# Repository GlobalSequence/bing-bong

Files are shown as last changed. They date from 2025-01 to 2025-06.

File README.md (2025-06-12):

[](https://github.com/GlobalSequence/bing-bong/blob/master/photo.png)

## Intro

Bing Bong is a digital drum synthesizer module for Eurorack synthesizers which generates percussive sounds using two different synthesis methods:

- Phase modulation synthesis
- Physical modeling synthesis

This module is intended to offer a versatile array of sounds ranging anywhere from organic substrates to purely synthesized tones. With a wide frequency range, it can fill many roles in an electronic drum kit. Both atonal and tonal sounds can be produced, ranging anywhere from quick transient bursts to long sustained sounds. 

## Block Diagram

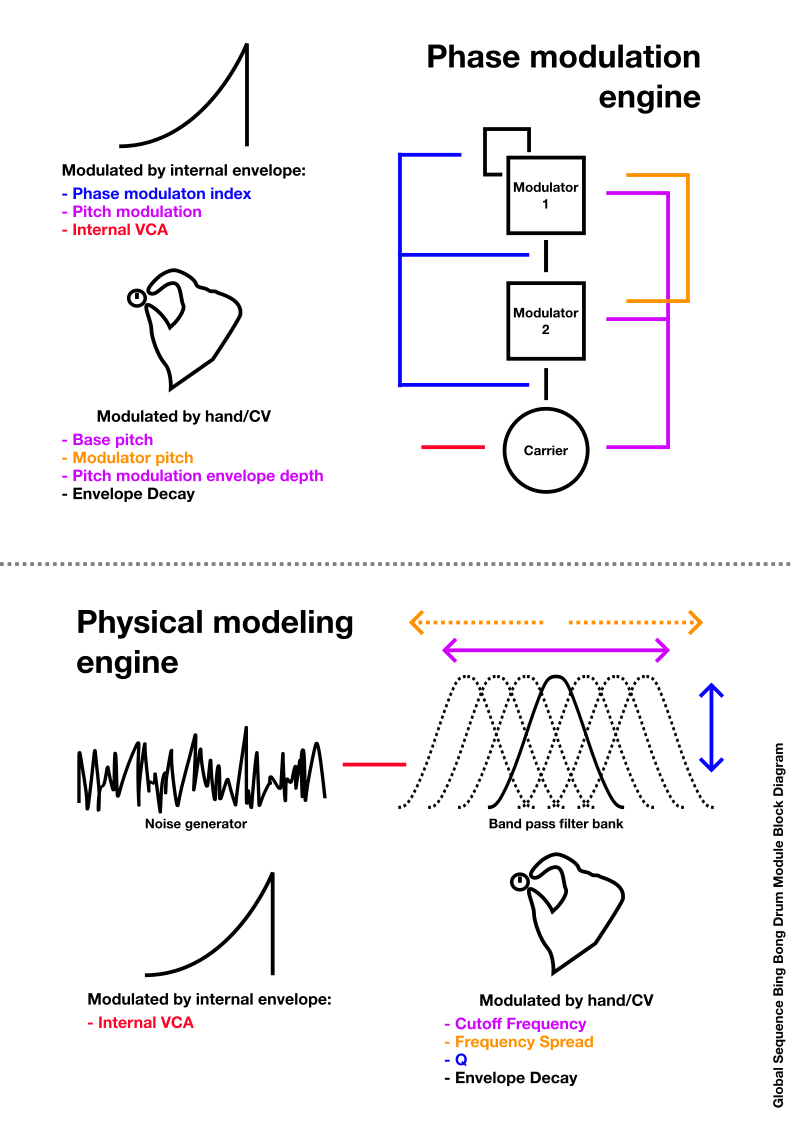
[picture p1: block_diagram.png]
[](https://github.com/GlobalSequence/bing-bong/blob/master/block_diagram.png)

## Features
- Versatile drum voice for modular synthesizers
- Switchable phase modulation and physical modeling sound engines
- Mechanical key switch for tactile manual triggering
- CV inputs for all parameters
- 12 bit, 48khz sound

## Synthesis Engines 
### Phase Modulation
#### Overview
The Phase modulation engine is made up of three sine wave operators, fed into one another in series, The first modulator has operator feedback.

The modulation index of each modulator is controlled by the envelope, with each index being set to maximum when the module is triggered, before fading to an index of 0 when the envelope has faded away, effectively creating a sharp sound which softens over time. 

This engine can be used to achieve deep raunchy kick drums, clean ringing chimes, metallic clangs, chirps, and more.
#### Parameters
##### Carrier 
This may be somewhat misleading as this parameter controls the base pitch of the entire voice. 
##### Modulator
Move the pitch of the two modulator oscillators relative to the pitch of the carrier oscillator. The first modulator is always an octave higher than the second modulator. 

When set very high, the carrier frequency (if also set very high) may push the modulator frequencies into interesting territories, or even to oblivion. There is no anti-aliasing in this module, and that's a feature, not a bug! 
##### Pitch Mod
Set the depth by which the envelope affects the pitch of all oscillators. With this parameter set to zero, there is no pitch modulation. As the pitch mod is turned up, the drum hit will start at increasingly higher frequencies and fall to the lowest frequency at the end of the envelope's decay.
##### Decay
Sets the decay time of the envelope. The envelope modulates these other parameters in the engine:
- Modulation index
- Pitch modulation amount
- Internal VCA
By shortening or lengthening the decay time, you can dramatically alter the trajectory of the sound, because all of the parameters dependent on it.

The decay time can be set from a few milliseconds to several seconds, turning the drum module into a sort of faux-drone that can be used for effects and sound scapes, should you wish to venture into that territory.

### Physical Modeling
#### Overview
The physical modeling engine is comprised of a white noise source which is fed into seven parallel band pass filters with a variable Q. 

This engine can be used to achieve organic drum tones ranging from membrane drums of many shapes and sizes, to percussive surfaces made of other materials like glass, metal, wood, and more. 
#### Parameters
##### Cutoff
This sets the cutoff frequency of the central and peripheral band pass filters. 
##### Spread
Pushes the 6 peripheral band pass filters away from the central filter. 3 peripheral filters are set to a lower frequency than the central filter, while the other 3 are higher. The second and third peripheral filters are twice and thrice as far from the central filter as the first on both the higher and lower end, meaning that the filters are always evenly spaced on the frequency spectrum.

When this parameter is set to zero, all of the filters are at the same frequency. 
##### Q
Sets the emphasis of all band pass filters using feedback. As the Q is turned, up, the center frequency of each filter is amplified to the point of self oscillation, making the atonal noise into distinct tones. 

Unlike the traditional VCF > VCA configuration of most modern synthesizers, the filters are set **after** the noise VCA, meaning that you can trigger a sound with a short decay, and if the Q is high enough, the sound will last longer than the decay.

WARNING: Setting the Q to a very high value will create a very loud self oscillation. Since the Q is independent of the decay, the only way to stop the self oscillation is to turn the Q down.
##### Decay
In the physical modeling engine, the envelope only affects the VCA of the voice, attenuating the sound of the filtered noise generator. As mentioned in the Q section, if the Q is set high enough, self oscillation will continue beyond the envelope decay. 

The decay time can be set from a few milliseconds to several seconds, turning the drum module into a sort of faux-drone that can be used for effects and sound scapes, should you wish to venture into that territory.

## DIY
### DISCLAIMER
This project is provided for informational and educational purposes only. By using the provided instructions, code, and hardware designs, you acknowledge that you are solely responsible for your own safety and the cost of any materials or components used.

If you find an error in the project that needs correction, please alert me and I will make it as soon as possible. 
### Build Guide
TODO: add more in depth instructions
#### Software flashing
The software can be uploaded directly to the MCU from the Arduino IDE. To add the Xiao RA4M1 board manager to your Arduino IDE installation, open Arduino Preferences, and add this to the "Additional boards manager URLs" section: https://files.seeedstudio.com/arduino/package_renesas_1.2.0_index.json
#### PCB Ordering
The hardware/gerbers folder contains three separate zip files, for each pcb of the build. Most PCB fabricators take a drag-and-drop upload method for zip files. Each file will likely have to be a separate purchase. 
#### Mounting the MCU board
The Xiao RA4M1 has castellated holes, allowing for the board to be mounted directly to the PCB, but I recommend instead using the optional 1x7 female pin headers marked as OPTIONAL in the BOM. 

This saves you from the headache of having to desolder the whole thing if anything ever goes wrong with the chip, and comes at the cost of the module being a little taller, but it's ultimately up to you. 

## Errata
This section serves as a TODO to me and a 'just so you know' to you.

- The mounting holes are spaced a bit too narrow, so if your Eurorack rails are fixed, you might have to widen the holes with a dremel or drill, or make the edits manually in KiCad. I plan to update the faceplate with oval mounting holes when there's time. 

 - If you have downloaded the PCBs for Bing Bong before 2025.03.25, there is an error where the Seeeduino Xiao board has SMT pads instead of THT pads. This causes the CV input to not connect to the analog pins on the Xiao board. If you have ordered a Bing Bong with the SMT pads instead of the THT pads, you can solder jumper wires to the following pins to the following components on the board which will connect the CV. 
     - Pin 2 - D2 or R10
     - Pin 3 - D3 or R18
     - Pin 4 - D4 or R24
     - Pin 6 - D5 or R30

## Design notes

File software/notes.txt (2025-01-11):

Add the Seeed Studio board manager to the Arduino IDE Preferences:

https://files.seeedstudio.com/arduino/package_renesas_1.2.0_index.json

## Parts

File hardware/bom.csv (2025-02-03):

Reference | Value | Footprint - Note: footprint sizes are not important. | Qty | Notes
AUDIO BOARD BOM
C1 | 1u | Capacitor_THT:C_Disc_D4.7mm_W2.5mm_P5.00mm | 1
C2,C3 | 10u | Capacitor_THT:CP_Radial_D5.0mm_P2.50mm | 2
C4,C5,C9,C10,C11 | 100n | Capacitor_THT:C_Disc_D4.7mm_W2.5mm_P5.00mm | 5
C6 | 4.7u - Bipolar Audio Cap | Capacitor_THT:CP_Radial_D5.0mm_P2.50mm - AUDIO CAPACITOR | 1 | Requires bipolar audio capacitor, not normal electrolytic or ceramic capacitors.
C7 | 100p | Capacitor_THT:C_Disc_D4.7mm_W2.5mm_P5.00mm | 1
C8 | 1n | Capacitor_THT:C_Disc_D4.7mm_W2.5mm_P5.00mm | 1
D1,D2,D3,D4,D5 | BAT85 | Diode_THT:D_A-405_P7.62mm_Horizontal | 5
J1 | Eurorack Power | Connector_IDC:IDC-Header_2x05_P2.54mm_Vertical | 1
J2,J3 | Conn_01x08_Pin | Connector_PinSocket_2.54mm:PinSocket_1x08_P2.54mm_Vertical | 2 | Female pin headers
Q1 | 2N3904 | Package_TO_SOT_THT:TO-92L_Inline_Wide | 1
R1,R9,R12,R14,R16,R20,R22,R26,R28 | 100k | Resistor_THT:R_Axial_DIN0207_L6.3mm_D2.5mm_P7.62mm_Horizontal | 9
R2,R4,R7,R8,R15,R17,R21,R23,R27,R29 | 10k | Resistor_THT:R_Axial_DIN0207_L6.3mm_D2.5mm_P7.62mm_Horizontal | 10
R3 | 2.2k | Resistor_THT:R_Axial_DIN0207_L6.3mm_D2.5mm_P7.62mm_Horizontal | 1
R5 | 33k | Resistor_THT:R_Axial_DIN0207_L6.3mm_D2.5mm_P7.62mm_Horizontal | 1
R6,R10,R18,R24,R30 | 1k | Resistor_THT:R_Axial_DIN0207_L6.3mm_D2.5mm_P7.62mm_Horizontal | 5
R11,R13,R19,R25 | 300k | Resistor_THT:R_Axial_DIN0207_L6.3mm_D2.5mm_P7.62mm_Horizontal | 4
U1 | SeeeduinoXIAO RA4M1 | Breakout Boards:Seeeduino XIAO-MOUDLE14P-2.54-21X17.8MM | 1 | Direct link: https://www.seeedstudio.com/Seeed-XIAO-RA4M1-p-5943.html
U2 | L7805 | Package_TO_SOT_THT:TO-220-3_Horizontal_TabDown | 1
U3 | TL071 | Package_DIP:DIP-8_W7.62mm_Socket | 1
U4 | TL074 | Package_DIP:DIP-14_W7.62mm_Socket | 1
U5 | MCP6004 | Package_DIP:DIP-14_W7.62mm_Socket | 1
 |  | 16 male pin headers | 1
OPTIONAL
 | Conn_01x07 | Connector_PinSocket_2.54mm:PinSocket_1x07_P2.54mm_Vertical | 2 | Female pin headers
 |  | 14 male pin headers | 1
CONTROL BOARD BOM
J1,J2,J3,J4,J5,J6 | ~ | Connector_Audio:Jack_3.5mm_QingPu_WQP-PJ398SM_Vertical_CircularHoles | 6
J8,J9 | Conn_01x08_Pin | Connector_PinSocket_2.54mm:PinSocket_1x08_P2.54mm_Vertical | 2
RV1,RV5,RV6,RV7 | 10k | Potentiometer_THT:Potentiometer_Bourns_PTV09A-1_Single_Vertical | 4
SW1 | SW_Push | Button_Switch_Keyboard:SW_Cherry_MX_1.00u_PCB | 1
SW2 | SW_SPDT | SPDT SPST Toggle Switch THIS ONE:SW_Toggle_Blue_wSlots | 1

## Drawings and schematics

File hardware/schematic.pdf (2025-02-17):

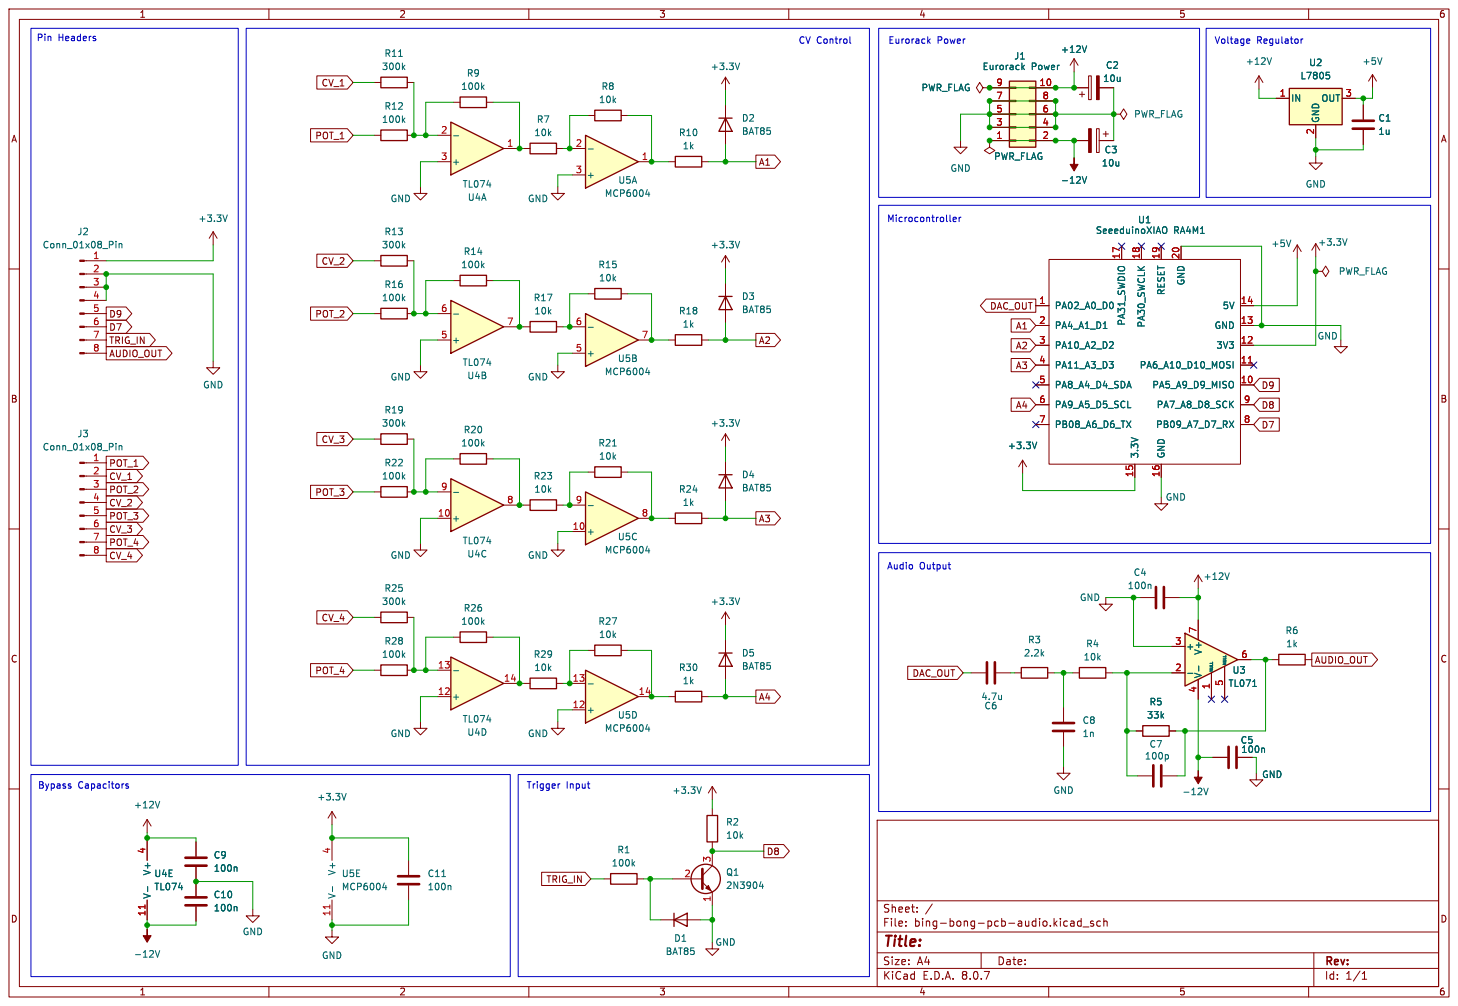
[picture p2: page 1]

Id: 1/1 Title: File: bing-bong-pcb-audio.kicad_sch Sheet: /

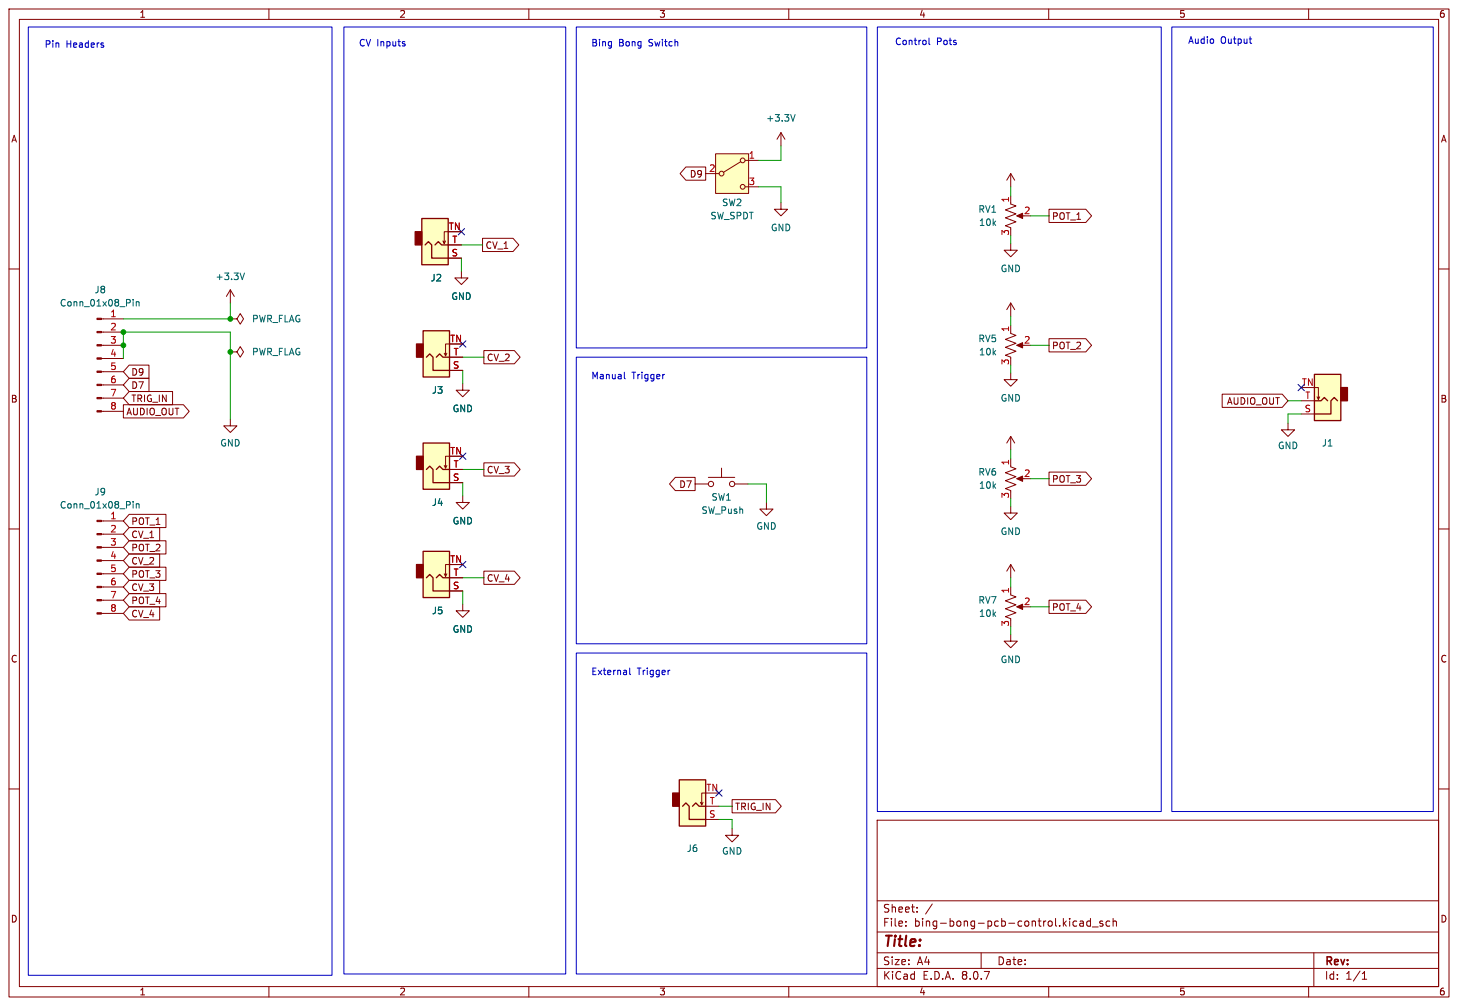
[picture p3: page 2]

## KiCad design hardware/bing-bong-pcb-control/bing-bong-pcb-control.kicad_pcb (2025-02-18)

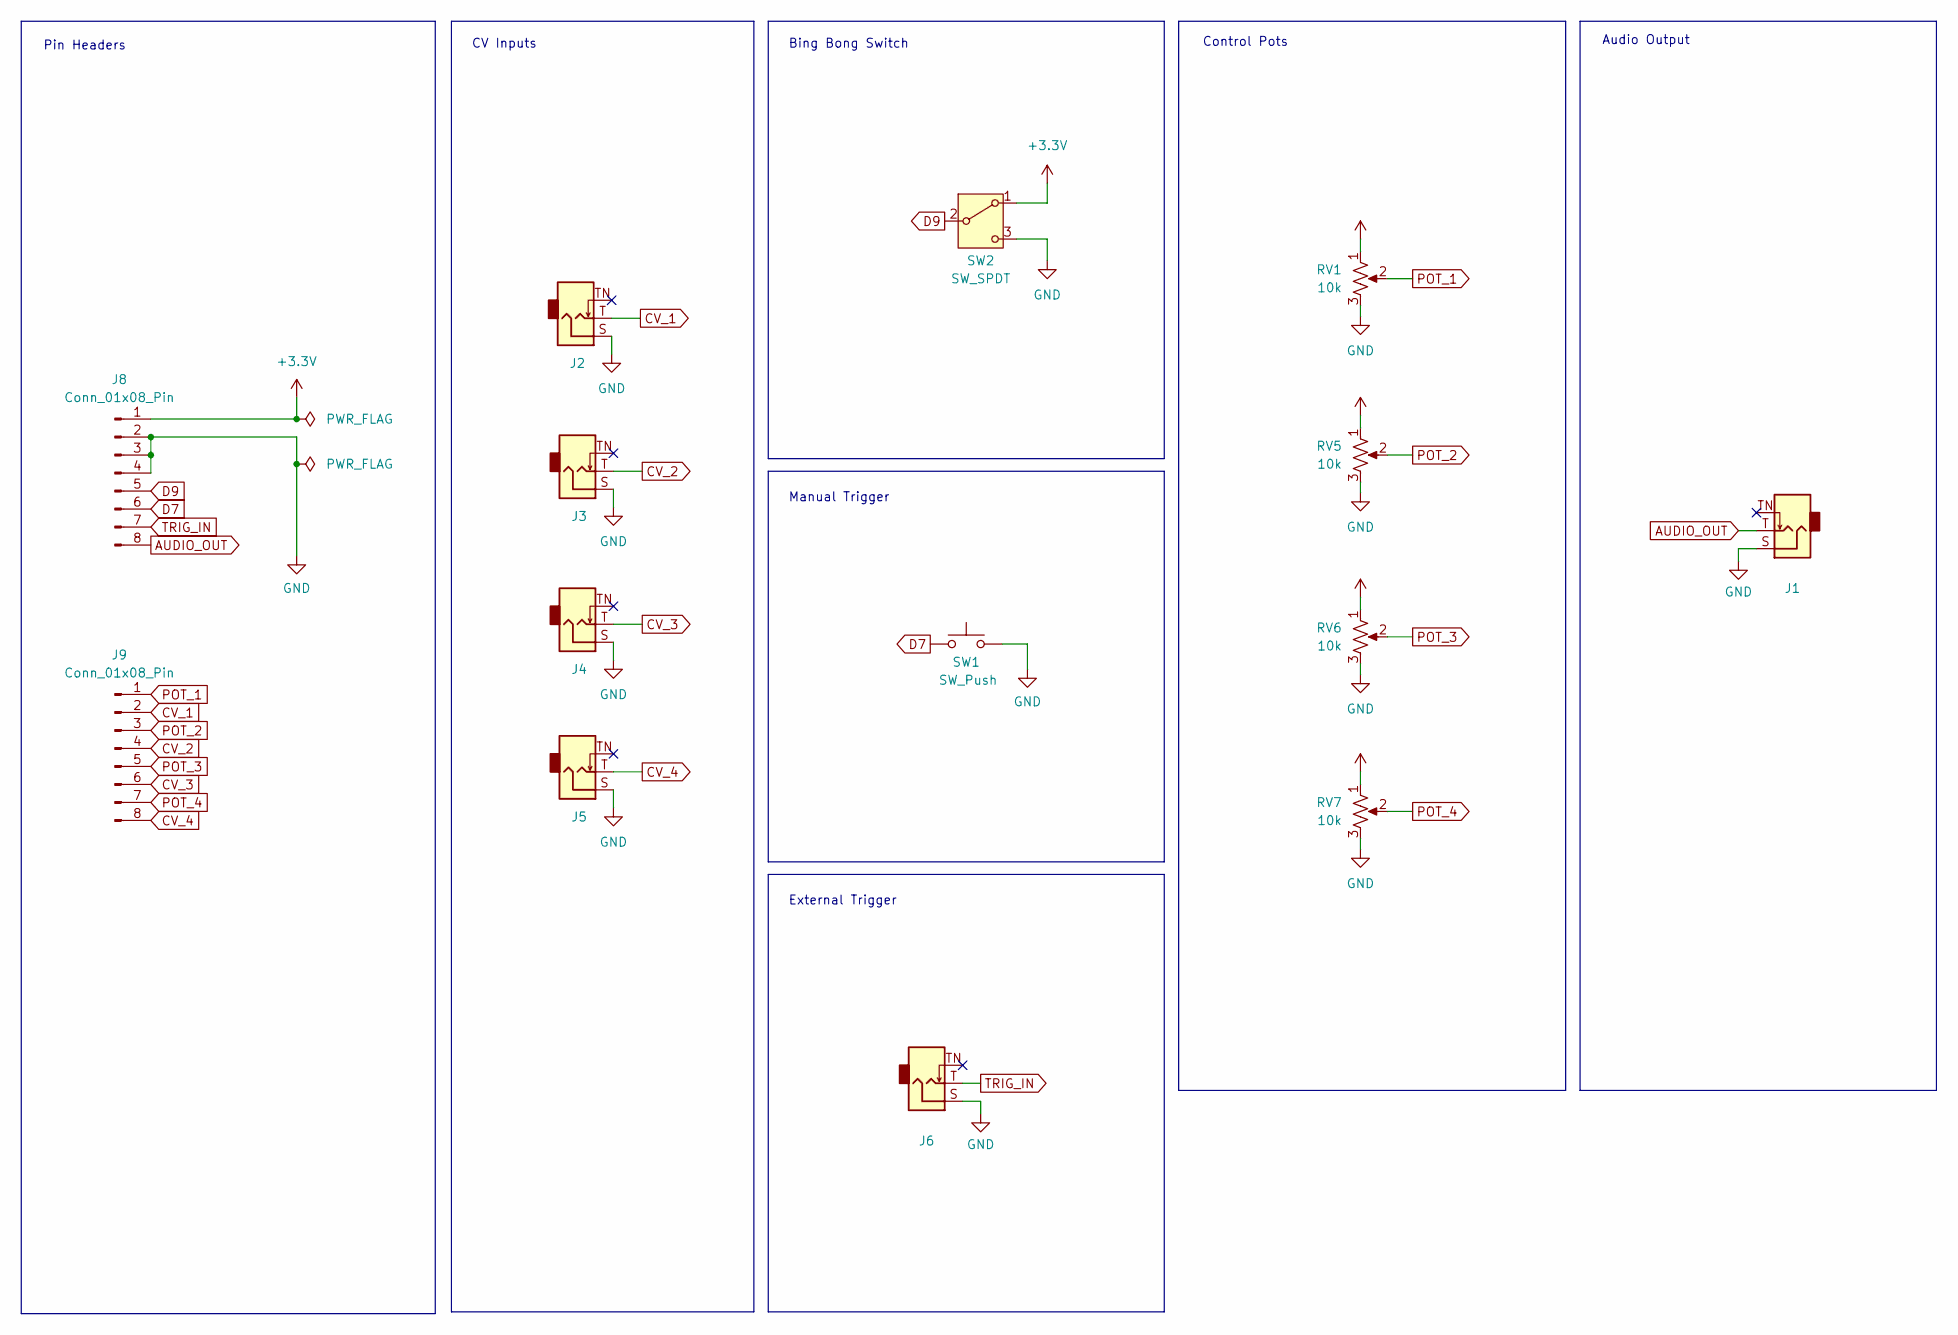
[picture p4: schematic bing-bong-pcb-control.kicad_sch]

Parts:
J1, J2, J3, J4, J5, J6: Jack_3.5mm_QingPu_WQP-PJ398SM_Vertical_CircularHoles
J8, J9: Conn_01x08_Pin; PinSocket_1x08_P2.54mm_Vertical
RV1, RV5, RV6, RV7: 10k; Potentiometer_Bourns_PTV09A-1_Single_Vertical
SW1: SW_Push; SW_Cherry_MX_1.00u_PCB
SW2: SW_SPDT; SW_Toggle_Blue_wSlots

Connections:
+3.3V: J8.1, RV1.1, RV5.1, RV6.1, RV7.1, SW2.1 (A)
AUDIO_OUT: J1.T, J8.8
CV_1: J2.T, J9.2
CV_2: J3.T, J9.4
CV_3: J4.T, J9.6
CV_4: J5.T, J9.8
D7: J8.6, SW1.1
D9: J8.5, SW2.2 (B)
GND: J1.S, J2.S, J3.S, J4.S, J5.S, J6.S, J8.2, J8.3, J8.4, RV1.3, RV5.3, RV6.3, RV7.3, SW1.2, SW2.3 (C)
POT_1: J9.1, RV1.2
POT_2: J9.3, RV5.2
POT_3: J9.5, RV6.2
POT_4: J9.7, RV7.2
TRIG_IN: J6.T, J8.7

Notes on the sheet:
Audio Output
Pin Headers
CV Inputs
Manual Trigger
External Trigger
Control Pots
Bing Bong Switch

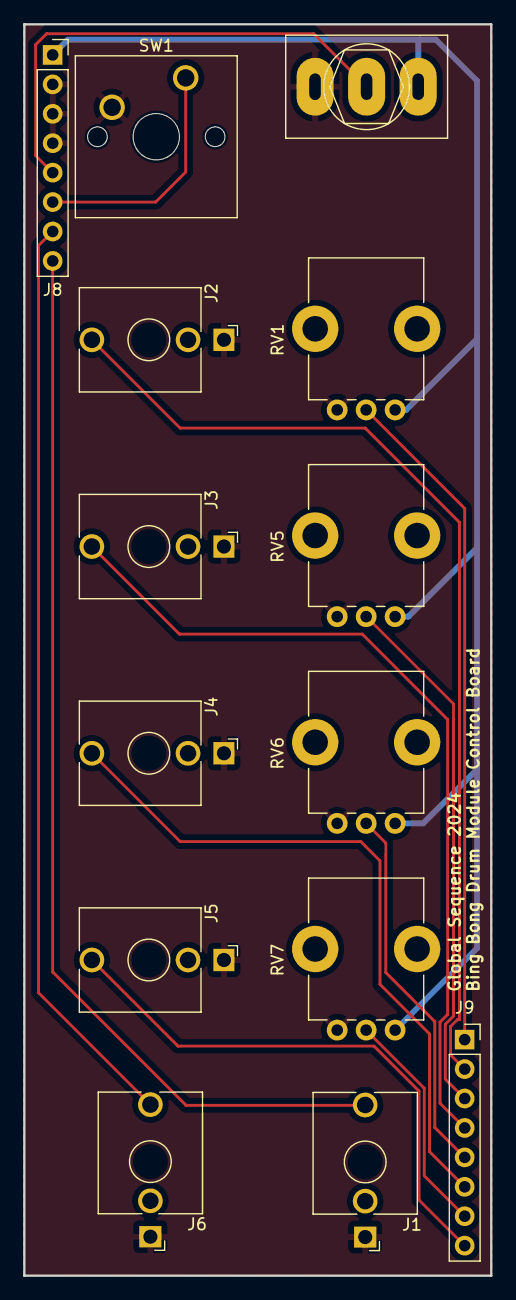
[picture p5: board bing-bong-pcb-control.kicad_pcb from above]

Board: 2 copper layers, 40.3 x 108.0 mm, 14 parts (0 on the bottom side), 14 nets.

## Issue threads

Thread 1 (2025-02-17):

Question: What should the gain of Audio Output opamp be?

dlakwi, 2025-02-17:
With the values of resistors R5 (33k) and R4 (100k) it looks like the gain would be 0.33.
If the RA4M1 DAC outputs [0 to 3.3v], then the output level would be ~1V pp.
Should these two values be swapped?
If so, the output level would be ~10V pp.

GlobalSequence, 2025-02-17:
Hi Donald,

Thank you for spotting that error! In the intended schematic, R4 is
actually 10k instead of 100k, while R5 remains 33k.

It's correct in the BOM and in the audio board specific schematic file, but
I somehow didn't change that error in the 'whole picture' schematic that
you're looking at.

Are you building a Bing Bong on breadboard/stripboard by chance?

On Mon, Feb 17, 2025 at 11:39 AM Donald Johnson ***@***.***>
wrote:

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

--
Cory Oleson
(707) 529-2392
***@***.***

dlakwi, 2025-02-17:
Thanks.
I didn't think to check the BOM and schematic in the audio board hardware files.
I had JLCPCB make the PCBs and Panel.

GlobalSequence, 2025-02-17:
The schematic has been updated to reflect the changes to the resistor value.

Hope you enjoy the module!

Closed 2025-02-17.

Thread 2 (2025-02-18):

Missing masks at SW2 mounting holes on Control PCB

dlakwi, 2025-02-18:
There is no front and back mask on the Control PCB at the Bing/Bong toggle switch SW2 around the mounting holes.

GlobalSequence, 2025-02-18:
By that do you mean that the solder pads for the switch would not be exposed? That's strange, this wasn't an issue when getting the PCBs made.

Is this an error from the manufacturer? If so can you show me a screenshot?

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

dlakwi, 2025-02-18:
Here are the KiCAD screenshots, with and without the F.Cu/B.Cu layers shown. Note the thin masking around the switch holes.

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

Here's a picture of the PCB (F) itself.

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

GlobalSequence, 2025-02-18:
Thank you for catching this. The KiCad library footprint itself was missing the masks. The fab I used must have fixed the error for me hence why I didn't have this issue.

This has been fixed and the gerber files updated. I threw the gerbers into JLCPCB to test.

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

Closed 2025-02-18.

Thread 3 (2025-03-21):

One Tone, no change but triggers works (also the trigger CV)

stilltryin, 2025-03-21:
Hey, not really sure where i went wrong: i get if there switch is on bing one sound (always the same) the pots not do anything put trigger works...any idea where to start to find the mistake. Used TL074CN, TL071ACP and MCP6004E/P. resoldered all and added the software again...but not sure if hard or software prob...thx

stilltryin, 2025-03-21:
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

GlobalSequence, 2025-03-21:
If the switch is doing nothing and neither are the pots, I'm wondering if either GND or 3.3v aren't making it to the control board somehow (most likely 3.3v). I would use a multimeter with the ground wire connected to the audio board. See if there's 3.3v on all of the potentiometer pins. If so, then test for continuity with the control and audio board ground planes.

If the control board isn't getting 3.3v, check the solder joint of the top-most pin-header (right next to the text "J2" in the picture) and the corresponding pin on the control board.

stilltryin, 2025-03-22:
ok will check today…also do i need to connect solder the bottom pins of the RA4M1 to the pcb?

stilltryin, 2025-03-23:
ok got 3.3v on the pots and after resoldering the Breakout i have also sound on both switch sides but i still cant change the sound with pots…also i wonder how to solder the breakout with pins? connect all or just outside lane? u think its hardware or could it be software (compiling or such)?

GlobalSequence, 2025-03-23:
> also i wonder how to solder the breakout with pins? connect all or just outside lane?
Can you elaborate on this? Unsure what you mean.

I'm looking at your picture and see that you've soldered the Xiao board directly to the PCB. It should work fine, but per the "Build Guide" section in the readme file of the Bing Bong project repository, I used pin headers to mount the Xiao so that it was removable. Looking at your photo, your Xiao board looks a little offset from the holes on the PCB.

I would check the following:
- The outputs of the op amps to make sure that they are producing the analog voltage that goes into the analog pins on the Xiao board. With the controller board attached, just see if there is a change in voltage when you turn the knob on the respective pin. For example turning Pot 1 affects pin A1, so check the first output of both the MCP6004 and the TL072. If there is no voltage from one or either op amp, this is where to begin investigating.
- If there is voltage gong out of the op amps, check A1 to see if the voltage is making it to the pin on the Xiao board. If Pot 1 is making a change on pin A1, then something is likely wrong with the chip.
- Check for continuity between A1 and the outside of R10. If there is voltage going out of the op amp output, but there is no voltage reaching Pin A1, then the board isn't soldered all the way to the PCB.

Let me know how it goes. If the software was uploaded unaltered, then it should be working.

stilltryin, 2025-03-25:
A1-A4's got no vias

KittenVillage, 2025-04-06:
I had some of these fabbed, just missed the fix by a day. My solution is going to be to use a 14 pin header, the old kind not the new round hole machine pin ones. Then I'll carefully bend them down to sit flat. ( See here: https://github.com/TOILmodular/GARGLER#soldering-ics-on-control-board ) Thencut the middle plastic and fit them onto header pins on the Xaio.  Should be enough room by the pads to attach wires for the fix.

Anyhow that's my plan for using my botched boards. I'll add pics in a couple of months when I get them done.

GlobalSequence, 2025-04-06:
Ah darn it, sincerely sorry to hear that. A little late to report but I have gotten the new boards in and can confirm that the Xiao footprint is now THT but still haven't built a board to test the whole thing.

Another alternative you can try is getting right angle female pin headers. Looks like 1x7's are common enough.

Parallel-Parallel, 2025-04-24:
Sorry jumping on this. The issue is me.  I made a comment somewhere else…but…super excited to build this. Built 4…none working yet. Just went through the list of trouble shooting above. I get 3.3v out at the pots. No sound when I trigger with button or trigger in. Checked continuity between boards…all ok. I suck at software stuff….but ran the software and got a 100% done. But …first Thanks for sharing this amazing module!!!!!

GlobalSequence, 2025-04-24:
Sorry to hear that you're having problems. I just built one of the new audio PCBs and can confirm that they work. I also re-uploaded the software to my Xiao with no issues.

Do you have an oscilloscope? I would work back from the MCU to see. Check pin D7 on the Xiao to see if the trigger is reaching it when you press the switch on the control board. You can do this part with a scope or a multimeter, really.

If a signal reaches the board, then check PA0 (DAC out) with a scope to see if there is any signal going out. If you are getting 3.3v on pin D7 when hitting the momentary switch (button) and nothing is coming out of PA0, then the problem may be with the Xiao or the software. If you do have signal coming out of pin PA0, then there may be a problem with the amplification stage.

Did you order your PCB after 3/25? By that I mean are the pads for the Xiao through hole? I would also check to see that CV coming from the pots are reaching the analog pins on the board.

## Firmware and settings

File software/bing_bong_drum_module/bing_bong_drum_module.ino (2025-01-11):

#include <AGTimerR4.h>
#include "ra4m1_dac_setup.h"
#include "analog_control.h"
#include "bing_bong_math.h"
#include "envelope.h"
#include "noise.h"
#include "pm_osc.h"
#include "svf.h"        

// buffer defines
#define BUF_LEN     (128)
#define NUM_BUF     (2)

// pin defines
#define NUMBER_OF_ANALOG_INPUTS 4
#define ADC_PIN1 A1
#define ADC_PIN2 A2
#define ADC_PIN3 A3
#define ADC_PIN4 A5_SCL
#define PUSH_PIN D7
#define TRIG_PIN D8
#define BING_BONG_PIN D9

// SVF Defines
#define NUMBER_OF_FILTERS 7
#define SPREAD_PARAM_MAX (12 * (ANALOG_TRUNCATED_BITS_TO_27B << 2))

// PM Oscillator Defines
#define NUMBER_OF_PM_OSCS 3

// output buffer
static volatile uint32_t out_buf[NUM_BUF][BUF_LEN] __attribute__((aligned(256)));

// SVF Variables
struct SVF_Variables svf_var[NUMBER_OF_FILTERS];
int8_t partial_spread_multiplier[NUMBER_OF_FILTERS] = {-3, -2, -1, 0, 1, 2, 3};

// PM Oscillator Variables
struct PM_Osc_Variables pm_var[NUMBER_OF_PM_OSCS];
uint32_t pm_env_amt_pitch;
uint32_t pm_env_amt_pm;

// envelope Params
struct Env_Params noise_env;
struct Env_Params pm_env;

// struct for noise variables
struct xorShiftVariables xor_s;

// DAC timer callback
void dacUpdate();
volatile bool buf_index;
bool last_buf_index;

// trigger
bool last_push_state;
volatile bool trig;
void trigIRQ() {trig = true;}

// analog input lock
LockPotParams l_pot[NUMBER_OF_ANALOG_INPUTS];

void setup() {
  // Serial.begin(115200);

  bingBongMathInit();
  analogReadResolution(12);

  buf_index = 0;
  last_buf_index = 1;

  // pinMode(4, OUTPUT); // speed test of buffering loop
  // pinMode(9, OUTPUT); // speed test of DAC ISR
  pinMode(PUSH_PIN, INPUT_PULLUP);
  pinMode(TRIG_PIN, INPUT_PULLUP);
  pinMode(BING_BONG_PIN, INPUT_PULLUP);
  attachInterrupt(TRIG_PIN, trigIRQ, FALLING);

  AGTimer.init(SAMPLE_RATE, dacUpdate);
  AGTimer.start();
  dacSetup();

  EnvInit(&noise_env);
  EnvInit(&pm_env);
  xorShift128Init(&xor_s);
}

void loop() {

  if(buf_index != last_buf_index) {
    last_buf_index = buf_index;
    // digitalWrite(4, HIGH);

  bool push = false;
  bool this_push_state = digitalRead(PUSH_PIN);
  if(this_push_state != last_push_state) {
      last_push_state = this_push_state;
      if(!this_push_state) {
          push = true;
      } 
  }
  
  if(push || trig) {
    trig = false;
    noise_env.value_ = 4095;
    EnvTrigger(RELEASE, &noise_env);
    EnvTrigger(ATTACK, &pm_env);
  }

    int a_read_1 = lockPotGetValue(analogRead(ADC_PIN1), millis(), &l_pot[0]);
    int a_read_2 = lockPotGetValue(analogRead(ADC_PIN2), millis(), &l_pot[1]);
    int a_read_3 = lockPotGetValue(analogRead(ADC_PIN3), millis(), &l_pot[2]);
    int a_read_4 = lockPotGetValue(analogRead(ADC_PIN4), millis(), &l_pot[3]);

    EnvUpdate(0, 0, 0, a_read_4 >> 5, &noise_env);
    EnvUpdate(4, 0, 0, a_read_4 >> 5, &pm_env);

    uint32_t noise_env_level = EnvRender(&noise_env) << 16;
    uint32_t pm_env_level = EnvRender(&pm_env) << 15;

    bool bing = digitalRead(BING_BONG_PIN);
    bool bong = !bing;

    if(bing) {
      pmDrum(a_read_1, a_read_2, a_read_3, pm_env_level);
    } else /* bong */{
      modalDrum(a_read_1, a_read_2, a_read_3, noise_env_level);
    }    
    // digitalWrite(4, LOW);
  }

}

void modalDrum(int c_param, int s_param, int q_param, uint32_t env_level) {

    int32_t cutoff = controlValBipolar(c_param);
    int32_t q = controlValPolar(q_param);
    int32_t spread = controlValPolar(s_param);

    for(int i = 0; i < NUMBER_OF_FILTERS; i++) {
      int32_t cutoff_spread_freq = ((spread >> 4) * partial_spread_multiplier[i]) + cutoff;
      SVFSetCutoff(cutoff_spread_freq, &svf_var[i]);
      SVFSetResonance(q, &svf_var[i]);
    }

    for(int i = 0; i < BUF_LEN; i++) {
        int32_t sample = 0;

        int32_t noise = ___SMMUL(xorShift128(&xor_s), env_level);
        for(int j = 0; j < NUMBER_OF_FILTERS; j++) {
            sample += SVFProcess(noise, BAND_PASS, &svf_var[j]) / NUMBER_OF_FILTERS;
            sample = __SSAT(sample, 31);
        } 
        out_buf[!buf_index][i] = __USAT((sample >> 16) + 2048, 12);
    }
}

void pmDrum(int c_param, int m_param, int p_param, uint32_t env_level) {

    int32_t pm_osc_carrier_freq = controlValBipolar(c_param);
    int32_t modulator_param_val = c_param + m_param - 1152;
    int32_t pm_osc_modulator_one_freq = controlValBipolar(modulator_param_val);
    // modulator_two base frequency is an octave up from modulator 1, 
    // which is 12 << 5 (7 bit freq table to 12 bit analog value);
    int32_t pm_osc_modulator_two_freq = controlValBipolar(modulator_param_val + 384);
    PMOscUpdateFreq(pm_osc_carrier_freq, &pm_var[0]);
    PMOscUpdateFreq(pm_osc_modulator_one_freq, &pm_var[1]);
    PMOscUpdateFreq(pm_osc_modulator_two_freq, &pm_var[2]);
    int32_t pm_env_amt_pitch = controlValPolar(p_param);

    const uint32_t pm_max_env_wave_val = ((1<<16) - 1) << 15;
    uint32_t pm_env_wave_modified = pm_env.stage_ == ATTACK? pm_max_env_wave_val : env_level;
    uint32_t pitch_mod_level = ___SMMUL(pm_env_wave_modified, pm_env_amt_pitch); 
    uint32_t pm_level = pm_env_wave_modified;
    uint32_t feedback_level = pm_level >> 1;

    for(int i = 0; i < NUMBER_OF_PM_OSCS; i++) {
        pm_var[i].freq += pitch_mod_level;
    }

    for(int i = 0; i < BUF_LEN; i++) {
        int32_t sample;
        static int32_t feedback;
        int32_t modulator_two = PMOscRender(___SMMUL(feedback, pm_level >> 1), &pm_var[2]);
        feedback = modulator_two;
        int32_t modulator_one = PMOscRender(___SMMUL(modulator_two, pm_level), &pm_var[1]);
        int32_t carrier = PMOscRender(___SMMUL(modulator_one, pm_level), &pm_var[0]);
        sample = ___SMMUL(carrier, env_level) << 1;
        out_buf[!buf_index][i] = (sample >> 16) + 2048;
    }
}

void dacUpdate() {
  static uint8_t buf_counter;
  uint8_t buf_sample_index;
  if(buf_counter < BUF_LEN) {
    buf_index = 0;
    buf_sample_index = buf_counter;
    // digitalWrite(9, HIGH);
  } else {
    buf_index = 1;
    buf_sample_index = buf_counter - BUF_LEN;
    // digitalWrite(9, LOW);
  }
  buf_counter++;
  *DAC12_DADR0 = out_buf[buf_index][buf_sample_index];
}

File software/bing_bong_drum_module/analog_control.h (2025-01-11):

#ifndef ANALOG_CONTROL_H
#define ANALOG_CONTROL_H

#include <stdio.h>
#define ADC_DEFAULT_RESOLUTION 12
// Define the analog resolution here 
// We choose 8 bits for a value 0-255
#define ADC_SCALED_RESOLUTION 8
#define Q28 1<<27
#define ANALOG_INPUT_TRUNCATION_BITS (ADC_DEFAULT_RESOLUTION - ADC_SCALED_RESOLUTION)
#define ANALOG_CONTROL_BIT_WIDTH (ADC_DEFAULT_RESOLUTION - ANALOG_INPUT_TRUNCATION_BITS)
#define ANALOG_CONTROL_MAX_VAL ((1 << ANALOG_CONTROL_BIT_WIDTH) - 1)
#define ANALOG_CONTROL_SHIFT_BITS 27 - (ADC_SCALED_RESOLUTION);

uint32_t controlValPolar(uint32_t input) {
    return (input >> ANALOG_INPUT_TRUNCATION_BITS) << ANALOG_CONTROL_SHIFT_BITS;
}

int32_t controlValBipolar(uint32_t input) {
    return (controlValPolar(input) - (1 << 26)) << 1;
}

uint64_t controlValMapPositive(uint64_t input, uint64_t in_max, uint64_t out_max) {
    return (input * out_max) / in_max;
}

const uint8_t lock_threshold = 48;
const uint8_t measure_threshold = 32;
const unsigned long time_out_length = 100L;

struct LockPotParams {
  bool locked = true;
  bool lock_clock_running;
  uint16_t last_val;
  uint16_t locked_val;
  uint8_t current_threshold;
  unsigned long clock_start_time;
};

uint16_t lockPotGetValue(uint16_t raw_val, unsigned long t, struct LockPotParams* l) {
  
  unsigned long time_elapsed = t - l->clock_start_time;
  if(!l->locked) {
    if(abs(raw_val - l->last_val) >= measure_threshold) {
      l->clock_start_time = t;
      // time_elapsed = 0;
      l->last_val = raw_val;
    }
    if(time_elapsed >= time_out_length) {
      l->locked_val = l->last_val;
      l->locked = true;
    }
    return raw_val;
  } else {
    if(abs(raw_val - l->locked_val) >= lock_threshold) {
      l->locked = false;
      return raw_val;
    } else {
      return l->locked_val;
    }
    return 0;
  }
}

#endif 

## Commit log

2025-01-09 created repository
    [bing-bong-pcb-audio-B_Cu.gbr, bing-bong-pcb-audio-B_Mask.gbr, bing-bong-pcb-audio-B_Paste.gbr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]
2025-01-11 added board manager notes in software directory
2025-01-12 added bom
    [bing-bong-bom.csv, bing-bong-pcb-audio.csv, bing-bong-pcb-control.csv]
2025-01-12 fixed bom
    [bing-bong-bom.csv]
2025-01-12 added missing references to pcb
    [bing-bong-pcb-audio-B_Cu.gbr, bing-bong-pcb-audio-B_Mask.gbr, bing-bong-pcb-audio-B_Paste.gbr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]
2025-01-12 changed cv resistor values
    [bing-bong-bom.csv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]
2025-02-02 added README, updated BOM
    [bing-bong-bom.csv, bing-bong-pcb-audio.csv]
2025-02-03 updated bom
    [bing-bong-pcb-audio.csv, bing-bong-pcb-control.csv, bom.csv]
2025-02-03 updated schematic
2025-02-17 updated schematic pdf file
2025-02-17 edited note in schematic file
2025-02-17 schematic updated to reflect pcb layout
2025-02-18 fixed missing mask on sw2
    [bing-bong-pcb-control-B_Cu.gbr, bing-bong-pcb-control-B_Mask.gbr, bing-bong-pcb-control-B_Paste.gbr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]
2025-03-25 changed smt pads on pcb to tht
    [bing-bong-pcb-audio-B_Cu.gbr, bing-bong-pcb-audio-B_Mask.gbr, bing-bong-pcb-audio-B_Paste.gbr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]
2025-03-25 corrected pin names
    [bing-bong-pcb-audio-B_Cu.gbr, bing-bong-pcb-audio-B_Mask.gbr, bing-bong-pcb-audio-B_Paste.gbr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]
